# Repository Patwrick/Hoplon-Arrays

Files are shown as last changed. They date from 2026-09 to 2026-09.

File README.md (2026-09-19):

# Hoplon-Arrays

Hoplon-Arrays is a modular cable-routing and cable-management system intended to fit underneath a desk. Silicone units snap onto a separate rigid, 3D-printed panel, which mounts to the desk underside with adhesive. Each unit has a rounded-square pad, a center column, and eight curved support fins. Stem-and-ball posts on the panel have four smaller alignment ribs; matching cores on the mold lid form sockets during casting.

**0.1.0 prototype source release candidate.** This snapshot includes the rev7 source, three checked print candidates, a socketless reference and proposed build instructions. The center-piece STL is withheld because mesh checks found zero-area triangles; there is no complete cleared printable mold set yet. See the [release notes](docs/release-notes.md) for what is included and what is deferred.

The current DIY material is **Shore 40A two-part silicone**; the owner's silicone and mounting-tape links are recorded in the [build guide](docs/build-guide.md#owner-used-materials). A complete physical build record, verified printing settings, and performance test record are still missing. This is a proposed pour-and-cure workflow.

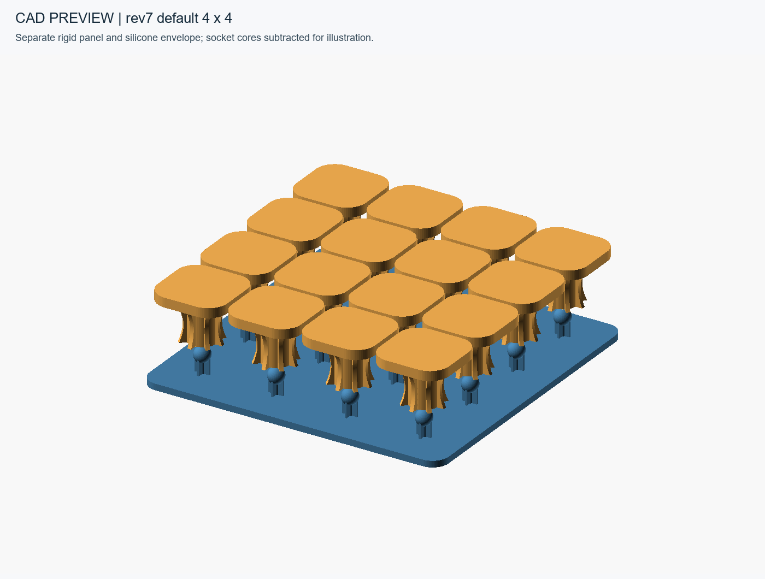
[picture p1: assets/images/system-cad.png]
CAD preview of the separate panel and an exploded array of units


*Current-source CAD preview, shown upright with units lifted above the panel for detail; installed units face downward beneath the desk. The illustration subtracts the shared post geometry to show intended sockets. It is not a photograph or evidence of successful casting.*

## Start here

1. Read the [validation status and file inventory](docs/validation.md) before choosing files. The original root-level STLs and legacy quote package are not the matched release set.
2. Follow the [build guide](docs/build-guide.md) for materials, calculated hardware, printing checks, a small compatibility trial, and the proposed casting sequence.
3. Use the [parameter guide](docs/parameters.md) and [validation commands](docs/validation.md#reproduce-the-checks) to inspect or customize the source. Resolve the center export before treating the outputs as a complete matched set.

You will need an appropriate 3D-printing workflow, measuring tools, mold-fastening hardware, the selected silicone manufacturer's technical and safety documentation, mixing equipment, mounting adhesive, and product-appropriate protective equipment. Product compatibility and printing settings remain to be tested and documented.

## What is included

| Part | Role | Current source / export |
| --- | --- | --- |
| Rev7 parametric source | Canonical mechanical design; millimeters | [system_rev7_perforated_score.scad](system_rev7_perforated_score.scad) |
| Center mold piece | Cavities, two face grooves, four bolt holes | Source mode `center_piece`; STL withheld; see [mesh issue](docs/validation.md) |
| Socket-core lid (`top_lid`) | Ball-and-rib cores enter silicone from the column side | [top_lid.stl](exports/rev7-default/top_lid.stl) |
| Pad-face lid (`bottom_lid`) | Closes the rounded-square pad face | [bottom_lid.stl](exports/rev7-default/bottom_lid.stl) |
| Separate rigid panel | Printed base with the mating post array; never part of the casting mold | [panel.stl](exports/rev7-default/panel.stl) |
| Silicone positive | Visual/cavity-construction envelope only; **no molded socket** | [silicone_positive_reference.stl](exports/rev7-default/silicone_positive_reference.stl); see [validation](docs/validation.md) |

The listed exports are computationally checked candidates for printing trials, not physically validated tooling. Resolve the center-piece mesh issue before treating them as a complete matched mold set. The default configuration is 4 × 4 on 23.4 mm pitch, with a 94.6 mm square panel and 130.6 mm square mold footprint. Scoring/perforation code exists but is **disabled in this set**. No female receivers, carrier array, retaining clips, nut traps, or ejector blocks are required.

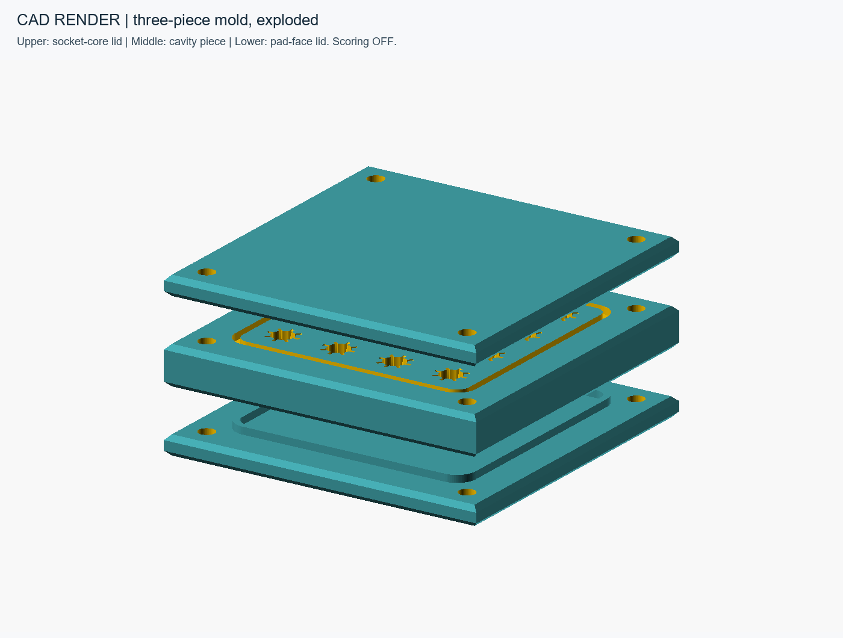
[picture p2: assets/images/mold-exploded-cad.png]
Exploded current-source mold render


*CAD render: socket-core lid above the cavity piece, pad-face lid below. Seating walls enter grooves; their height is not extra closed-stack thickness.*

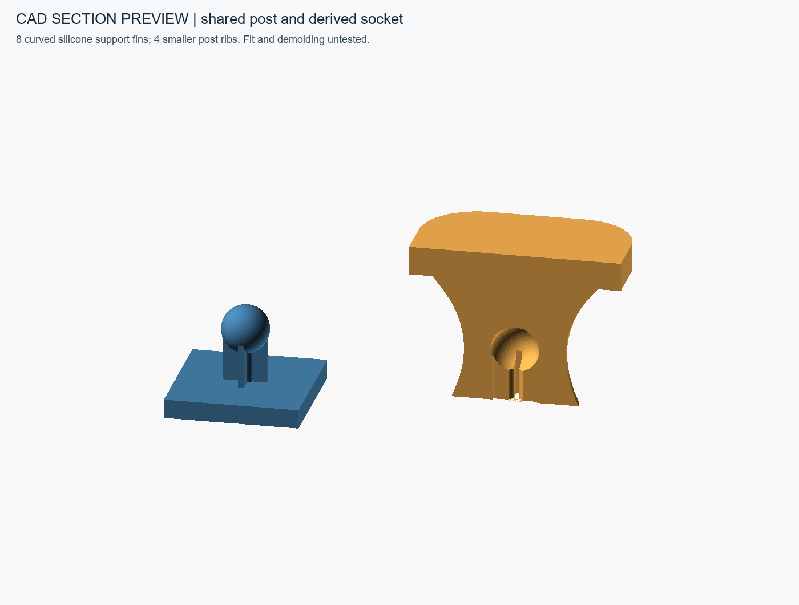
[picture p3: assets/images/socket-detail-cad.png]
CAD cutaway of a socket and the shared post geometry


*Illustrative cutaway derived from the source modules. The four post ribs are distinct from the eight larger silicone support fins. Rendering does not establish fit, release, or durability.*

## Build overview

After resolving the center export and validating a complete matched set, print and inspect the three mold pieces and separate panel. Dry-fit the stack and hardware, then run a small silicone/surface/fit trial. With the pad-face lid beneath the center piece and the column openings accessible, fill before lowering the core lid. Cure according to the chosen product documentation, open the mold, carefully release the sockets, inspect/trim flash, and trial-fit units onto the panel. See the [complete proposed sequence](docs/build-guide.md), including unverified air escape and demolding limits.

The panel's flat back faces the desk underside and the silicone array faces downward. Adhesive-fitting slits in the panel back are a **planned change**, absent from the current CAD and exports; their dimensions and effect on the 2 mm panel need review. Adhesion to the actual desk finish and cable retention are not yet documented as validated.

A demonstration video is planned for a future update. It will show under-desk mounting, cable routing and adjustment, and relevant build steps; no video is available yet. See the [photo and video handoff](docs/photos.md).

## Contributing, evidence, and license

For a geometry or build report, provide the source hash, all parameter overrides, export tool version, affected mode, measurements and units, and reproducible steps. For a physical trial, include material product and batch, print/process settings, and privacy-checked photos. Distinguish source changes, preview artifacts, mesh defects, and fit observations; intentional intersections within Boolean unions are not automatically errors. Propose mechanical changes separately with before/after evidence.

Original project materials are offered under the custom [Hoplon-Arrays Personal and Noncommercial License](LICENSE.md). Personal hobby use, modification and free sharing are permitted with attribution and retained notices. **Business use, including internal business use, sales and paid manufacturing are not licensed** without separate written permission from the applicable rights holder. Third-party materials keep their own terms.

These are custom terms, not an open-source or standard Creative Commons license. Their reach depends on the rights the licensor actually holds; they do not guarantee exclusive control of functional physical parts. See [licensing scope and limitations](docs/licensing.md), and the [release checklist](docs/release-checklist.md) for outstanding publication gates.

The [photo handoff](docs/photos.md) lists the missing physical evidence and reproducible CAD images. [AGENTS.md](AGENTS.md) gives concise maintenance rules.

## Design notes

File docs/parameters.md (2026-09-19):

# Rev7 source and parameters

The canonical design for this preparation is the root [system_rev7_perforated_score.scad](../system_rev7_perforated_score.scad), unchanged during documentation work. The older copy inside the quote package is a different configuration. No original Customizer JSON preset or recorded export override file was found. Comments such as “change to 20” are history, not active parameter values.

All dimensions below are millimeters. The recorded source SHA-256 is `52bff07c70fd33cc4247b62ed5b2c33dbb560772f9617580dee63a37e3ac0839`; this fingerprints the audited working-file bytes, including line endings. The [export manifest](../exports/rev7-default/manifest.json) records every top-level assignment as source text, including derived expressions. Its assignments are provenance, not a Customizer preset. Only `tool_mode` was overridden for the generated candidates. See [validation](validation.md) before treating any candidate as printable.

## Active geometry

| Parameter / result | Current value | Meaning |
| --- | ---: | --- |
| `rows`, `cols` | 4, 4 | 16 separate silicone units / 16 posts |
| `top_size`, `top_corner_radius` | 22, 6 | Rounded-square pad size and corner radius |
| `top_thickness`, `top_bevel_inset` | 3, 0 | Pad thickness; no pad bevel inset |
| `unit_height` | 16 | Silicone positive overall height |
| `edge_gap_x`, `edge_gap_y` | 1.4, 1.4 | Pad-edge gaps |
| `pitch_x`, `pitch_y` | 23.4, 23.4 | Center-to-center array pitch |
| `field_margin_x`, `field_margin_y` | 1.2, 1.2 | Margin beyond outer pads |
| `field_w`, `field_d`, `field_corner_radius` | 94.6, 94.6, 5 | Panel / field outline |
| `column_d` | 9 | Central silicone column diameter |
| Column height | 13 | `unit_height - top_thickness` |
| `fin_count`, `fin_thickness` | 8, 1.2 | Curved silicone support fins; distinct from post ribs |
| `fin_attach_bot_frac`, `fin_attach_top_frac` | 0.60, 0.80 | Fin outer radii 6.6 at column end and 8.8 at pad end |
| `fin_root_overlap`, `fin_end_overlap` | 0.35, 0.20 | Intentional overlaps that join fins to column/pad |
| `fin_neck_extra`, `fin_steps` | 0.10, 40 | Curved-fin profile control and sampling |
| `$fn`, `EPS` | 72, 0.001 | Circular tessellation and Boolean epsilon |

The support-fin profile extends to z = 13.2 in the upright positive and intentionally enters the pad that begins at z = 13. That overlap is part of the union. It is not an unintended loose body or proof of an invalid final solid.

## Shared attachment geometry

Both `top_lid_snap_posts()` and `panel_part()` call **the same `ball_snap_post()` module**. The lid mirrors these posts into the silicone cavity; the separate panel presents them outward for attachment.

| Parameter / result | Current value |
| --- | ---: |
| `snap_stem_d`, `snap_stem_h` | 1.6, 6 |
| `snap_ball_d`, `snap_ball_sink` | 5, 0.4 |
| Ball-center distance from mounting face | 5.6 |
| Nominal post depth / height | 8.1 |
| `snap_fin_enable`, `snap_fin_count` | true, 4 |
| `snap_fin_thickness`, `snap_fin_outer_d` | 0.6, 4.6 |
| `snap_fin_stem_overlap`, `snap_fin_base_overlap` | 0.12, 0.10 |
| `snap_fin_top_clearance`, `snap_fin_tip_taper` | 0.10, 0 |
| Alignment-fin local z limits | −0.10 to 5.50 |
| `panel_thickness` | 2 |
| Nominal panel including posts | 94.6 × 94.6 × 10.1 |

The 72-segment exported ball reaches approximately 8.09762 mm above its mounting face, slightly less than its nominal 8.1 mm extent. Matching CAD posts do not establish a workable printed socket fit: shrinkage, surface finish, cure and printer error remain untested. The source positive **does not subtract this core**, so `silicone_positive` is a visual reference, not a finished socket-bearing part.

## Mold and fastener geometry

| Parameter / result | Current value |
| --- | ---: |
| `mold_wall`, `clamp_flange` | 0, 18 |
| `tool_w`, `tool_d` | 130.6, 130.6 |
| `lid_thickness` | 8 each |
| Center thickness | 16 |
| `mold_edge_bevel` | 2 |
| `cavity_face_relief` | 0.08 |
| `fit_clearance` | 0.20 |
| `bleed_channel_w`, `bleed_channel_depth` | 3, 3 on both faces |
| Seating-wall nominal section | 2.6 wide, 3 high; 0.2 clearance at each side |
| `bolt_hole_enable`, count | true, 4 aligned through-holes |
| `bolt_hole_d`, `bolt_edge_margin` | 6.7, 7.5 |
| Hole center coordinates | x = ±54.45, y = ±54.45 |
| Hole center spacing | 108.9 × 108.9 |
| Closed stack at bolt line | 8 + 16 + 8 = **32** |

The closed assembly uses center z = 0…16, bottom-lid exterior z = −8, and top-lid exterior z = 24. The walls nest inside the center's channels; their 3 mm heights must not be added again to the bolt stack. Export-wrapper z positions differ from assembled positions: bottom lid 0…11; center 0…16; top lid approximately 0.00238…16.1. These file heights are not additive for fastener sizing.

The 6.7 mm CAD hole is a clearance hole, not an M6.7 thread. A calculated candidate is four M6 × 45 bolts (under-head length), four matching M6 nuts and eight flat washers. The [build guide](build-guide.md#bolt-length-and-clearance) records the standards-based washer/nut assumptions, length calculation and required fit trial. There are no nut traps. A 12 mm washer outside diameter fits on the outer planar face: each bolt center is 8.85 mm from the bevel's planar boundary, giving 2.85 mm margin beyond a 6 mm radius washer. Check actual head/washer dimensions and printed surfaces before purchase/use.

There are perimeter overflow trenches on both center faces and matching seating walls. There is **no dedicated injection port or explicit local vent channel from each cavity to those perimeter trenches**. Filling and air escape during closure remain a physical test requirement.

## Scoring features are currently off

`score_enable = false`, `score_top_enable = false`, and `score_bottom_enable = false`. Therefore none of the matched scoring teeth or pockets appears in the audited default set. `score_dot_enable = true` alone does not activate them.

The dormant values are: offset 1.2, continuous line width 0, pocket depth 0.60, web target 0.08, derived tooth height 0.52, fit clearance 0.20, dot diameter 0.80, side-dot pitch 4 and column-side dot count 18. These are experimental controls, not a demonstrated tear specification. Activating them requires coordinated regeneration of the center and corresponding lids and inspection for unintended collisions, clearance and flash behavior. Do not turn them on merely to match an older filename.

## Modes and customization

| `tool_mode` | Result |
| --- | --- |
| `silicone_positive` (source default) | 16 separate solid external positives; sockets absent |
| `center_piece` | Cavity block; current STL quality gate unresolved |
| `top_lid` | Socket-forming core lid and seating wall |
| `bottom_lid` | Pad-face closure and seating wall; no block ejectors |
| `panel` | Separate rigid panel with 16 posts |
| `exploded_mold` | Visual assembly reference only |
| `exploded_system` | Visual mold, solid positives and separate panel |

The source's final `else` also selects `exploded_system` for an unrecognized string; a typo can silently export the wrong scene. The supplied export script restricts modes to named individual parts/reference models.

To explore a change, retain the canonical file and work on a clearly named local copy. Record all overrides, regenerate every affected mating part, and repeat dimensional, topology and physical-fit checks. Row/column count, pitch, pad/column dimensions, posts, channels and score settings are mechanically coupled. No supported parameter range or tolerance budget has been validated. Keep the original external pad/column/eight-fin structure unless an owner-approved mechanical change explicitly replaces it.

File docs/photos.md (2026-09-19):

# Photos, CAD images and future video

No physical prototype photos were present in the inspected repository. The three current images are generated from the canonical source, with no photographic or test claims. Do not substitute the old quote drawings or concept art for current-model evidence.

## Existing CAD images

| File | View and caption | Location |
| --- | --- | --- |
| [system-cad.png](../assets/images/system-cad.png) | CAD preview: separate rigid panel and lifted 4 × 4 silicone array; shared post geometry subtracted for illustrative sockets | README main image |
| [mold-exploded-cad.png](../assets/images/mold-exploded-cad.png) | CAD render: core lid / center piece / pad-face lid in assembly orientation, separated for visibility; default scoring off | README and build-guide orientation reference |
| [socket-detail-cad.png](../assets/images/socket-detail-cad.png) | CAD preview section: derived socket and shared ball post; eight support fins versus four post ribs | README and build-guide fit reference |

Run `python scripts/render_cad.py --openscad openscad` from the repository root (OpenSCAD and Pillow required). The script reads the unchanged SCAD and replaces only its view dispatch in a temporary file. The system scene lifts socketed unit envelopes 10 mm above their nominal panel seating plane. The socket illustration subtracts `ball_snap_post()` from `silicone_unit()` and cuts away half for visibility; that is a documentation view, not a new production source mode. The exploded mold uses the source assembly modules with spacing for visibility. The script does not edit the SCAD.

The [render manifest](../assets/images/render-manifest.json) records the source hash, OpenSCAD version, scenes, camera settings, and output hashes. Main/detail images use OpenCSG previews; the exploded mold uses CGAL rendering. Previews may have display artifacts. The rendered images have been opened and checked visually; they contain no desktop, faces, labels from private correspondence, or copied image metadata. Each is freshly written as an RGB PNG without source EXIF or location fields.

## Photos still needed

These filenames are planned handoff names, not links to missing files. Save reviewed copies under `assets/images/` only after removing private details and metadata. Preserve unredacted originals outside the public repository.

| Planned filename | View | Proposed caption | Placement | Must demonstrate |
| --- | --- | --- | --- | --- |
| `panel-assembled-photo.jpg` | Under-desk three-quarter and side view with routed cables | Physical cable-management prototype under a desk, [material/product], [test date], [configuration] | README main image beside CAD | Desk attachment, separate rigid panel and attached units, cable path and clearance; no performance inference |
| `panel-adhesive-photo.jpg` | Panel back before mounting and its contact with the desk underside | Adhesive mounting trial with [tape identity], [desk finish], [configuration] | Build-guide mounting step | Actual tape layout, contact area and access; identify whether any future slits are present |
| `unit-separated-photo.jpg` | Single demolded unit, pad and underside | One cast Shore 40A unit before assembly | Build guide inspection | Rounded-square pad, center column, eight curved support fins; scale included |
| `socket-post-photo.jpg` | Macro of socket beside a post, additional underside angle | Molded socket and four post alignment ribs | README attachment detail / fit step | Socket opening and keyed recesses; all four ribs identifiable across views; defects visible |
| `mold-three-pieces-photo.jpg` | Both faces of all three printed pieces | Printed mold parts, labeled by contacting silicone face | Build guide orientation | Core lid, center cavity openings, pad-face lid, both bleed grooves and seating walls |
| `bolt-stack-dry-fit-photo.jpg` | Side of closed stack plus one measured corner | Dry fit with four through-bolts, washers and nuts | Build guide hardware | Measured 32 mm nominal corner stack, seated faces, actual head/washer clearances and thread projection |
| `mold-open-fill-photo.jpg` | Center on pad-face lid before closing, then partly lowered core lid | Proposed filling sequence in a documented trial | Build guide filling | Open cavity access, fill level and observed air/overflow paths; panel outside mold |
| `demolding-photo.jpg` | Lid opening and socket being gently released in separate frames | Physical demolding trial, [material/process] | Build guide demolding | Actual release direction, ball undercut, tool placement and any tears or broken posts |
| `flash-detail-photo.jpg` | Macro before and after trimming with scale | Flash result, scoring [off / exact enabled configuration] | Build guide flash / validation | Flash thickness/bridges, any scoring marks and damage; manual trimming distinguished from tearing |

Capture an uncropped context view as well as each close-up. Record source hash, parameters, printer/material/process, silicone product, cure schedule, release treatment, and trial outcome alongside the image. Avoid identifiable people, shipping labels, supplier screens, correspondence, home/work location, serial numbers, and background reflections. Inspect EXIF/GPS, author fields, filenames, embedded thumbnails, and visible text before publication. Obtain permission for any identifiable person or third-party image. A cleaned image does not remove private metadata from older Git objects or original copies.

## Future demonstration video

The owner plans to add a video in a future update. No recording or public URL is available yet; do not add a broken embed or present the CAD views as filmed results. A suggested working filename is `hoplon-arrays-under-desk-demo.mp4`, with the public caption “Hoplon-Arrays: under-desk mounting and cable routing — [configuration/date].” Add its reviewed link to the README and build guide once available.

Suggested sequence:

1. Establish the underside of the desk, the cable route and the intended panel location.
2. Show the separate panel, one silicone unit and the snap/socket interface; identify the actual silicone and adhesive used.
3. Show the panel back, adhesive placement and mounting. If adhesive-fitting slits have been added in a later revision, identify that revision rather than implying the current files contain them.
4. Demonstrate placing, adjusting and removing cables, showing the panel attachment and unit behavior without claiming an unmeasured load or life rating.
5. Include short build clips if available: three mold pieces, open filling, cure conditions, demolding and flash inspection. Label any unfilmed steps as proposed.

Record the source/configuration, material batches, desk finish, print settings and relevant measured results in the video description. Review visible backgrounds, screens, shipping labels, audio, faces and video/container metadata before publication. Use only owned or authorized footage/music. A demonstration documents the shown trial; it does not establish general performance.

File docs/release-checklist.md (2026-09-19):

# 0.1.0 release candidate checklist

**Prepared scope: first prototype source release, 0.1.0. Publication is not authorized.** The owner has requested preparation with the current files and later updates. [Release notes](release-notes.md) and [changelog](../CHANGELOG.md) make that limited scope explicit. No push, tag, hosted release, visibility change, history rewrite, staging or commit is part of this preparation. The review archive is a file allowlist, not a Git history export.

## Publication blockers / owner decisions

- [ ] Approve public disclosure and the exact proposed files in [release-files.txt](release-files.txt). Review the actual ZIP and its `REVIEW-MANIFEST.json` before publishing.
- [x] Add the owner-requested personal/noncommercial license, excluding business and profit-making permission. [LICENSE.md](../LICENSE.md) and the [scope notes](licensing.md) distinguish CAD/hardware, scripts, documentation and assets, preserve third-party terms and explain functional-hardware limits.
- [ ] Confirm the authority to license each included contribution and its required attribution. The custom license is added; ownership and third-party clearance are not established by adding it. Legal review of the wording is advisable, particularly for physical-product restrictions. Do not describe this restricted-use project as open source.
- [ ] If publishing Git history, approve or remediate its owner-linked author attribution. Deletion or `.gitignore` changes cannot remove old Git objects. If attribution must change, review a separately authorized, backed-up history-remediation plan first; no rewrite has been run. The curated file archive contains no Git author metadata.
- [ ] If publishing Git history, review the intended branch and reachable objects explicitly. Earlier captured/local objects still retain excluded legacy material, including an embedded personal path; auxiliary refs and reflogs change as local tools operate. The refreshed audit found prepared-file snapshots in current auxiliary refs and older legacy objects retained locally, including unreachable objects. Do not publish the `.git` directory, a mirror or an all-ref bundle. No local objects or refs have been purged.
- [x] Exclude the entire original legacy quote package from this candidate. STEP geometry and drawings are unverified and differ from current SCAD; an earlier overlap concern remains unresolved. The bundled executable and bytecode also have privacy/redistribution concerns. They remain private local references pending any separate review.
- [x] Prepare the current files as a prototype source release with the limitations in [validation](validation.md) documented. The center STL and physical validation are deferred; they prevent a complete-printable-kit or proven-build claim, not preparation of this honestly limited source snapshot. Mechanical changes remain separate proposals.
- [ ] Authorize publication explicitly. Preparing this candidate does not authorize publishing the repository or archive.

## Before claiming a demonstrated DIY build

- [ ] Resolve the center-piece export's zero-area triangles and validate a complete matched set before advertising a complete printable mold download. This requires an explicit export/triangulation investigation; no automatic mesh or mechanical repair was applied.
- [x] Record the owner-approved under-desk cable-management purpose and owner-used silicone/adhesive links in the [build guide](build-guide.md#owner-used-materials).
- [ ] Confirm the supplied BBDINO 40A variant and record matching official technical/SDS revisions. Complete unresolved product-specific fields in the [build guide](build-guide.md).
- [ ] Record printer/material/process and verified orientations; inspect sealing, post/rib detail, support access and dimensions.
- [ ] Dry-fit the calculated four M6 × 45 mm fasteners, four nuts and eight washers with the actual hardware. Confirm the 32 mm nominal bolt-line stack, full lid seating, head/washer clearance and thread engagement.
- [ ] Run a surface/cure compatibility sample and one-cavity fill, demold and snap-fit trial. Observe air escape, complete pad/fin fill, release from the ball cores and any damage.
- [ ] Measure overflow and handling loss before selecting a full casting batch. Use documented product density before any volume-to-mass conversion.
- [ ] If enabling scoring, regenerate a matched set and test interference, flash and trimming. Default scoring is off. No precise/tool-free tear is demonstrated.
- [ ] Confirm exact mounting-tape identity/dimensions and manufacturer application guidance; trial adhesion to the actual printed panel and desk finish before making mounting or cable-load claims.
- [ ] Add the physical evidence in [photos](photos.md), including failures and dimensions. Complete physical tests before changing claims; CAD checks alone do not certify printability, fit, cure compatibility, durability, or suitability for a particular use.

These process items may remain openly documented prototype limitations if the owner approves a prototype-only source release; they block claims of a proven build.

## Preparation checks

- [x] Record `0.1.0` in [VERSION](../VERSION), prepare [release notes](release-notes.md) and a [changelog](../CHANGELOG.md), and identify the mechanical design as rev7.
- [x] Original CAD, STLs and quote assets retained in place. No original geometry changed.
- [x] Canonical source and default values read; old exports distinguished from regenerated ones.
- [x] Local current/staged/untracked files and locally available Git objects/metadata inspected. Detailed redacted audit evidence kept outside the publishable repository.
- [x] No likely credentials found by the local checks performed. This is bounded scan coverage, not a guarantee. Any subsequently discovered real credential requires owner rotation/revocation as well as cleanup.
- [x] Current-source images generated and reviewed; original physical photos were absent. New image metadata checked.
- [x] Quote package and original root STLs excluded by explicit archive allowlist and local ignore rules. Ignore rules are not history cleanup.
- [x] Harden archive construction to reject changed source/assets, failed or unmanifested export candidates, path traversal and symlink/junction paths. Preserve SCAD and binary bytes with [Git attributes](../.gitattributes).

The local audit included normal branch refs, auxiliary capture refs, reflogs, all available objects, commit identity fields, and local origin configuration. Remote server state, hosted releases, LFS servers, forks, other clones, and cloud copies were not accessed. New captured objects or refs may be created by local tooling after the audit; recheck immediately before any Git publication. Original CAD/STEP/PDF metadata and the bundled executable received supported local inspection; see the private audit handoff for exact limitations. Never upload private originals to a scanning service.

## Build and inspect the review archive

The [packaging script](../scripts/package_review.py) checks local Markdown targets/anchors, the exact file list, and source/export/image hashes against the provenance manifests. It rejects failed or unrecorded mesh/image assets and symlinks/junctions. `--check` performs validation without writing a ZIP. `--output` requires a new ZIP path **outside the repository**, writes the checked file bytes plus an internal manifest, then rereads the archive to check names, CRCs and member hashes. The manifest records the proposed version; it does not imply that a Git tag or release exists. The script refuses overwrites and never publishes.

```sh
python -B scripts/package_review.py --check
python -B scripts/package_review.py --output ../Hoplon-Arrays-release-review/Hoplon-Arrays-0.1.0-prototype-review.zip
```

After any edit, create a new candidate filename and inspect it again. Do not zip the repository directory wholesale: `.gitignore` does not control an arbitrary ZIP operation. Exclude `.git`, originals/backups, supplier correspondence, raw/private audits, executable installers and bytecode. Review staged changes independently before an eventual commit.

## Publication handoff after owner approval

1. Approve the exact package contents, rights/attribution and applicable Git-history scope above. Preserve the excluded originals and private review records.
2. If publishing the repository, stage only the explicit paths in `release-files.txt` after removing its comment lines; inspect that exact staged set and approve a commit. Do not use a blanket add or publish auxiliary refs. No files are staged by the preparation scripts.
3. Use the reviewed `0.1.0` notes for the initial prototype release and identify it as a prerelease/experimental snapshot. Create a tag or hosted release only after explicit authorization; use an explicitly approved branch/ref for any push.
4. Attach the inspected curated archive and its checksum, rather than an unreviewed working-directory ZIP. Check the final hosted files and links after publication. Replace the notes' "not yet published" status and changelog's prepared status only when publication actually occurs.

The missing photos/video, slit design, selected-product process documents and physical tests remain future work. Do not silently turn those omissions into assertions of validation when preparing the public description.

## Optional improvements after the gates

- Add physical build photos and measured results as evidence becomes available.
- Add the planned under-desk demonstration video when available, following the [photo/video handoff](photos.md#future-demonstration-video).
- Review the planned panel-back adhesive-fitting slits, establish dimensions and validate a new panel revision before documenting them as implemented. See the [pending geometry proposal](validation.md#planned-panel-mounting-change).
- Add a selected-product batch worksheet once density and measured losses are known.
- Expand mesh checks with an independent self-intersection/solid validator and slicer review.
- Add tested print profiles and a reproducible compatibility/retention test protocol.
- Consider geometry changes only through a separately reviewed proposal with affected files, measured defects and validation criteria.

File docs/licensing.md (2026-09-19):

# Licensing and reuse

The owner requested permission for personal/noncommercial use without granting business or profit-making use. [LICENSE.md](../LICENSE.md) implements that direction with **custom terms**. It is not a standard Creative Commons license or an open-source license. This page explains the scope; the license text contains the operative terms.

| Material | Applied terms / limit |
| --- | --- |
| Original SCAD and released CAD exports | Personal/noncommercial license, to the extent the rights holders can grant permission |
| Original Python scripts | Same license; personal execution, modification and free sharing permitted, business use excluded |
| Original documentation and CAD images | Same license with attribution and preserved notices |
| Physical parts made from the design | Personal making/use and free gifts are permitted under rights the Licensor holds; no business or paid manufacturing permission is granted |
| Third-party dependencies, websites, product documents and separately licensed material | Their own terms; not relicensed by this project |
| Excluded legacy quote package and unverified original assets | Not added to the public package or granted redistribution permission by this change |

For permitted sharing, credit **Hoplon-Arrays**, retain the license and existing notices, identify changes, and include the source repository link when available. No personal name, new company owner or public contact address has been invented. For use outside the grant, obtain separate written permission from the applicable rights holder; none is included here.

## Why custom terms

Creative Commons' NonCommercial condition considers the purpose of a use; an entity's for-profit status alone does not decide whether it complies. CC also recommends against applying its licenses to software. The owner's request excludes business use itself, including internal use, and covers CAD plus scripts, so this project uses explicitly labeled custom wording. [CC NonCommercial explanation](https://creativecommons.org/faq/#does-my-use-violate-the-noncommercial-clause-of-the-licenses), [CC software guidance](https://creativecommons.org/faq/#can-i-apply-a-creative-commons-license-to-software)

Business-use restrictions are incompatible with the Open Source Definition; describe the project as available for personal/noncommercial use, not open source. [Open Source Definition, section 6](https://opensource.org/osd)

## Legal limits and contribution review

A license cannot create rights its licensors do not hold. In particular, US copyright law limits protection of the mechanical/utilitarian aspects of useful articles; copyright in drawings does not automatically provide an exclusive manufacturing right. Consequently, this license alone does not guarantee control over every commercial use of the physical cable-management hardware. No patent or registered design right has been verified for this project. [U.S. Copyright Office: useful articles](https://www.copyright.gov/register/va-useful.html)

This is custom drafting, not a legal opinion or a guarantee of enforceability. Legal review is advisable before relying on it, particularly for restrictions concerning functional hardware. Before publication, confirm the authority to license every included contribution and preserve applicable third-party notices. Before accepting future contributions, confirm the contributor is entitled and willing to offer them under these terms; ownership is not automatically assigned to the maintainer. Publication, identity/privacy review and mechanical-validation gates remain separate from adding a license.

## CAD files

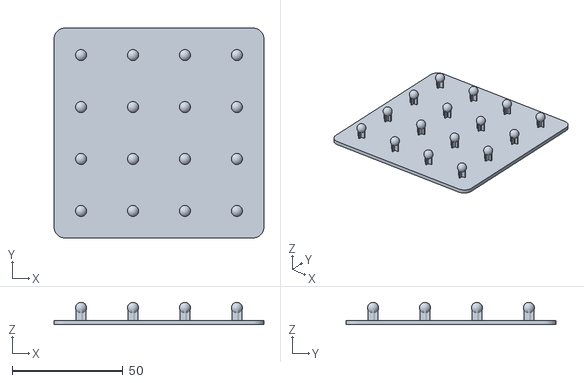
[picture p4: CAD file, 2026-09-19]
exports/rev7-default/panel.stl
94.6 x 94.6 x 10.1

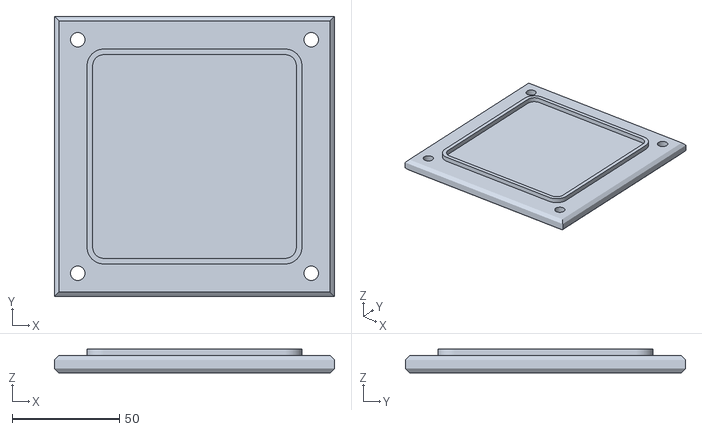
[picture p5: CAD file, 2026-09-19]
exports/rev7-default/bottom_lid.stl
130.6 x 130.6 x 11.0

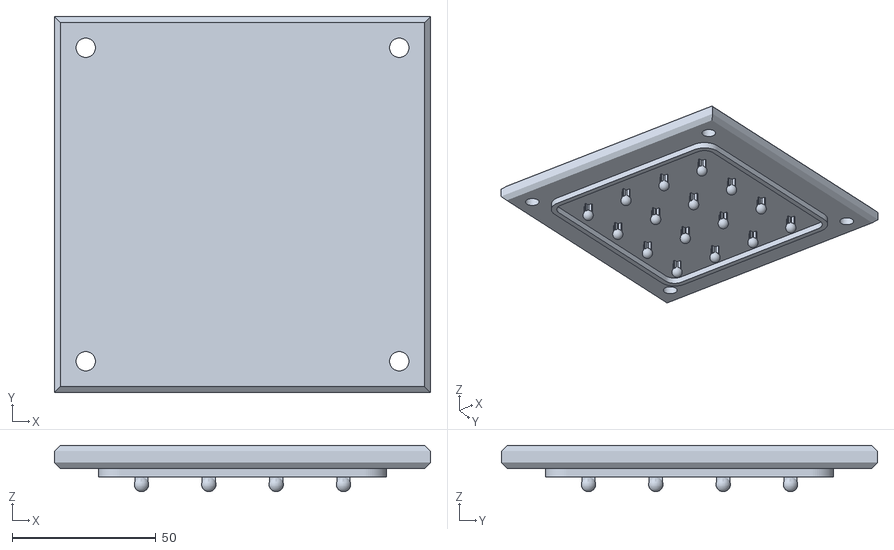
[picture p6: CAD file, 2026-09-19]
exports/rev7-default/top_lid.stl
130.6 x 130.6 x 16.1

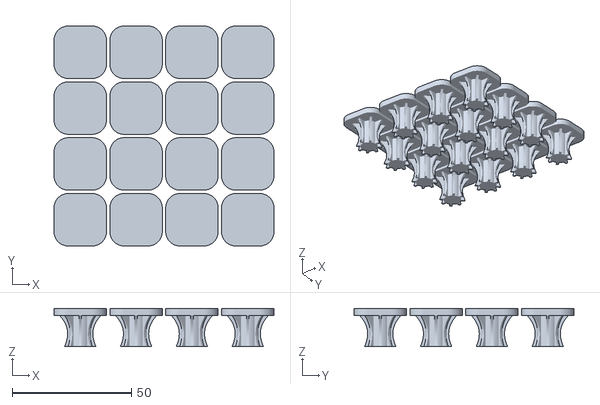
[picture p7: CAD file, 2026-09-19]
exports/rev7-default/silicone_positive_reference.stl
92.2 x 92.2 x 16.0

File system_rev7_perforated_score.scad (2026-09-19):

// Cleaned clip-unit + mold + panel system
//
// What this version does:
// - Removes the molded panel backing entirely.
// - Keeps the original pad + column + fin unit structure.
// - Adds a separate PRINTED panel with ball-snap posts.
// - Uses ball-post geometry directly on the TOP LID to create molded snap sockets.
// - Uses the same ball-post geometry on the final printed panel.
// - Adds 4 alignment fins/ribs on each ball-post stem for orientation/keying.
// - No insert carrier array is used in this revision.
// - The bottom lid is flat.
// - The center mold has bleed channels on BOTH faces.
// - Both lids get matching seating walls that fit into the bleed channels.
// - Adds real matched score teeth + pockets around the top and bottom parting-face edges.
// - Variables are grouped at the top and unused legacy modules were removed.
//
// Suggested workflow:
// 1) Print top lid, center piece, bottom lid.
// 2) Fill/close mold with silicone in the cavities; overflow gets captured in bleed channels.
// 3) The top-lid ball posts create the pop-in/pop-out socket shape in the silicone.
// 4) Demold the silicone units.
// 5) Print the separate panel with the same ball-post array and snap the silicone units onto it.

$fn = 72;
EPS = 0.001;

// ============================================================
// TOOL / VIEW
// ============================================================
tool_mode = "silicone_positive";
// "silicone_positive", "center_piece", "top_lid", "bottom_lid",
// "panel", "exploded_mold", "exploded_system"

show_exploded_gap = 18.0;

// ============================================================
// ARRAY / UNIT GEOMETRY
// ============================================================
rows = 4;
cols = 4;

top_size          = 22.0; //change to 20, already printed top_lid.
top_corner_radius = 6.0;
top_thickness     = 3.0; //3.4
top_bevel_inset   = 0.0;

unit_height       = 16.0;

edge_gap_x        = 1.40; //1.2
edge_gap_y        = 1.40; //1.2
pitch_x           = top_size + edge_gap_x;
pitch_y           = top_size + edge_gap_y;

field_margin_x    = 1.2;//3.8
field_margin_y    = 1.2;
field_corner_radius = 5.0;

// ============================================================
// COLUMN / FIN GEOMETRY
// ============================================================
column_d             = 9.0;//8
fin_count            = 8;
fin_thickness        = 1.2;
fin_neck_extra       = 0.10;
fin_attach_bot_frac  = 0.60; //0.60
fin_attach_top_frac  = 0.80; //0.99
fin_root_overlap     = 0.35;
fin_end_overlap      = 0.20;
fin_steps            = 40;

// ============================================================
// MOLD GEOMETRY
// ============================================================
mold_wall          = 0.0; //4.0
clamp_flange       = 18.0;
lid_thickness      = 8.0;

// Chamfer on outside edges of center_piece, top_lid, and bottom_lid.
// This gives a small pry/spatula lead-in at the mold split lines.
mold_edge_bevel    = 2.0;

// Tiny overcut at the two mold faces to prevent exact-coplanar preview skins
// from making the center-piece cavities look closed.
cavity_face_relief = 0.08;

fit_clearance      = 0.20;

bleed_channel_w    = 3.0;
bleed_channel_depth= 3.0; //3.0

// Flash scoring / perforation control.
// Previous revision made a gutter, which could make the flash thicker.
// This version creates MATCHED mold teeth + pockets. The remaining silicone
// between them is controlled by score_web_thickness, like dotted rip-paper.
score_enable          = false; // true
score_top_enable      = false;   // silicone top-pad side / bottom_lid side
score_bottom_enable   = false;   // ball-post/column side / top_lid side //true

score_offset          = 1.2;   // distance from actual part edge before score line begins
score_line_width      = 0.0;   // width of continuous score rib
score_pocket_depth    = 0.60;   // depth of matching pocket cut into center piece
score_web_thickness   = 0.08;   // silicone left between lid tooth and center pocket
score_tooth_height    = max(score_pocket_depth - score_web_thickness, EPS);

score_fit_clearance   = 0.20;   // extra XY clearance so score teeth fit into pockets
score_dot_enable      = true;   // adds dotted/perforated rip-paper style teeth
score_dot_d           = 0.80;
score_dot_pitch       = 4.00;   // spacing for square-side dots
score_dot_count       = 18;     // circular dots around column/ball side

bolt_hole_enable   = true;
bolt_hole_d        = 6.7; //6.8
bolt_edge_margin   = 7.5;

// shared ball-snap post geometry
// Used on BOTH the top lid and the final printed panel.
snap_stem_d        = 1.6;
snap_stem_h        = 6; //1.8
snap_ball_d        = 5.0;
snap_ball_sink     = 0.4;  // how much the ball blends into the stem 0.6

// 4 alignment fins/ribs that run up the stick toward the ball.
// Used on BOTH the top lid and the final printed panel because both use ball_snap_post().
snap_fin_enable        = true;
snap_fin_count         = 4;
snap_fin_thickness     = 0.6;  // tangential fin thickness
snap_fin_outer_d       = 4.6;   // how far the fins extend outward from the stem center
snap_fin_stem_overlap  = 0.12;  // radial overlap into the stem so fins print as one body
snap_fin_base_overlap  = 0.10;  // z-overlap into lid/panel surface for stronger base fusion
snap_fin_top_clearance = 0.10;  // gap before ball blend area
snap_fin_tip_taper     = 0.00;  // top of fin narrows slightly as it reaches the ball
// ============================================================
// PANEL GEOMETRY
// ============================================================
// The final panel uses the SAME ball-post structure as the top lid.
panel_thickness       = 2.0;

// ============================================================
// DERIVED
// ============================================================
field_w = (cols - 1) * pitch_x + top_size + 2 * field_margin_x;
field_d = (rows - 1) * pitch_y + top_size + 2 * field_margin_y;

tool_w  = field_w + 2 * mold_wall + 2 * clamp_flange;
tool_d  = field_d + 2 * mold_wall + 2 * clamp_flange;

pad_top_face_size = max(top_size - 2 * top_bevel_inset, 0.1);
pad_top_face_r    = max(top_corner_radius - 0.55 * top_bevel_inset, 0.25);

snap_post_drop = snap_stem_h - snap_ball_sink + snap_ball_d / 2;

bolt_x = tool_w / 2 - bolt_edge_margin - bolt_hole_d / 2;
bolt_y = tool_d / 2 - bolt_edge_margin - bolt_hole_d / 2;

// ============================================================
// HELPERS
// ============================================================
function clamp(v, lo, hi) = min(max(v, lo), hi);
function bez2(t, p0, p1, p2, p3) = [
    pow(1 - t, 3) * p0[0] + 3 * pow(1 - t, 2) * t * p1[0] + 3 * (1 - t) * pow(t, 2) * p2[0] + pow(t, 3) * p3[0],
    pow(1 - t, 3) * p0[1] + 3 * pow(1 - t, 2) * t * p1[1] + 3 * (1 - t) * pow(t, 2) * p2[1] + pow(t, 3) * p3[1]
];
function bezier_pts(p0, p1, p2, p3, steps=16) = [for (i = [0:steps]) bez2(i / steps, p0, p1, p2, p3)];
function fin_angles(n) = [for (i = [0 : n - 1]) i * 360 / n];

module rounded_rect_2d(w, d, r) {
    rr = clamp(r, 0.01, min(w, d) / 2 - 0.01);
    offset(r = rr)
        square([max(w - 2 * rr, 0.01), max(d - 2 * rr, 0.01)], center = true);
}

module rounded_square_2d(s, r) {
    rounded_rect_2d(s, s, r);
}

module field_outline_2d() {
    rounded_rect_2d(field_w, field_d, field_corner_radius);
}

module place_units() {
    for (r = [0 : rows - 1])
        for (c = [0 : cols - 1])
            translate([
                (c - (cols - 1) / 2) * pitch_x,
                (r - (rows - 1) / 2) * pitch_y,
                0
            ])
                children();
}

module bleed_channel_2d() {
    difference() {
        offset(delta = bleed_channel_w)
            field_outline_2d();
        field_outline_2d();
    }
}

module seal_wall_2d(clearance = fit_clearance) {
    difference() {
        offset(delta = max(bleed_channel_w - clearance, EPS))
            field_outline_2d();
        offset(delta = clearance)
            field_outline_2d();
    }
}

module corner_bolt_holes(z0, h) {
    if (bolt_hole_enable && bolt_hole_d > EPS)
        for (sx = [-1, 1])
            for (sy = [-1, 1])
                translate([sx * bolt_x, sy * bolt_y, z0])
                    cylinder(h = h, d = bolt_hole_d);
}

module beveled_tool_body(h) {
    b = clamp(mold_edge_bevel, 0, min(min(tool_w, tool_d) / 2 - EPS, h / 2 - EPS));
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

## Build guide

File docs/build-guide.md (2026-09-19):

# DIY build guide: Shore 40A silicone

This is a **proposed prototype workflow**, derived from the current rev7 CAD. A documented physical casting, print profile, socket-fit trial, and Shore 40A performance test have not been established. Review [validation](validation.md) before buying materials or printing. This is a two-part silicone pour-and-cure process; the older industrial LSR quote workflow is not the DIY process.

The intended application is cable routing and management underneath a desk. The rigid panel attaches to the desk underside using mounting adhesive, with the silicone units facing downward. The owner has identified the materials used below; this records their selection without claiming a documented load, adhesion or durability test.

### Owner-used materials

| Material | Owner-provided product link | Documentation status |
| --- | --- | --- |
| Silicone | [BBDINO 40A clear silicone kit, ASIN B0FHHBGSQK](https://www.amazon.com/dp/B0FHHBGSQK) | Matches the manufacturer's 1.1 kg / 2.42 lb 40A clear product; nominal manufacturer specifications and remaining documentation gaps are below. |
| Panel mounting adhesive | [Mounting tape, ASIN B0FPQ3VWPB](https://www.amazon.com/dp/B0FPQ3VWPB) | Owner-reported panel adhesive; confirm exact tape grade, supplied dimensions and application instructions from its packaging/manufacturer. |

Links were checked on 2026-09-19 and have shopping-history/tracking parameters removed. These are product references, not affiliate links or evidence of supplier endorsement. Verify the supplied variant and batch; a marketplace listing is not a substitute for a matching technical datasheet or SDS.

The adhesive listing needs clarification: its selected title/variant says 0.39 inch × 10 feet, while shared details mention 2 inch / 50 mm width. The title invokes 3M, but the brand/manufacturer fields identify P7yaumy, and the title and bullets disagree on removable versus permanent bonding. Treat this as the owner's exact purchase reference, not a verified 3M grade. Measure the actual roll and confirm packaging/instructions before sizing the planned slits or specifying installation conditions. No attributable manufacturer instructions were located for this tape during this review. [Owner-linked tape listing](https://www.amazon.com/dp/B0FPQ3VWPB)

## 1. Choose a matched set

Use the root [rev7 source](../system_rev7_perforated_score.scad), the configuration in [parameters](parameters.md), and the regenerated exports listed in [validation](validation.md). Do not combine the original root-level STLs, quote-package files, or differently sized exports with this set. A filename or a comment that a lid was printed does not establish matching dimensions.

**Current gate:** the regenerated center-piece STL has zero-area triangles and is withheld from the printable-download list. Resolve and validate that export before a full build; the following is a proposed procedure for a complete matched set, not a claim that all required print files are cleared.

The default model has 16 units in a 4 × 4 array. Each unit has a nominal 22 × 22 mm rounded-square pad, 3 mm pad thickness, 16 mm overall height, a 9 mm center column, and **eight curved support fins**. The distinct attachment post has **four small alignment ribs**. Unit pitch is 23.4 mm in both directions. Dimensions are millimeters; STL does not encode units, so verify the slicer imports millimeters without scaling.

| Part | Quantity | Purpose / source mode |
| --- | ---: | --- |
| Center piece (export withheld) | 1 | Printed cavity tooling; source mode `center_piece`; resolve [mesh issue](validation.md) first |
| [Top lid](../exports/rev7-default/top_lid.stl) | 1 | Printed tooling carrying socket-forming ball cores; `top_lid` |
| [Bottom lid](../exports/rev7-default/bottom_lid.stl) | 1 | Printed pad-face closure; `bottom_lid` |
| [Rigid panel](../exports/rev7-default/panel.stl) | 1 | Separate final component carrying attachment posts; `panel` |
| Owner-linked BBDINO 40A two-part silicone | Trial, then measured batch | Product link above; manufacturer instructions, quantity and compatibility still require verification |
| Owner-linked panel mounting tape | Amount/layout to establish in a mounting trial | Applies to the rigid panel back and desk underside; not silicone or mold assembly |
| M6 × 45 mm fully threaded bolts, 1 mm pitch | 4 | Calculated candidate, under-head length; see below |
| Matching M6 nuts, 5 mm thick for this calculation | 4 | External nuts; no modeled nut traps |
| M6 flat washers, 6.4 mm ID × 12 mm OD × 1.6 mm thick | 8 | One under each bolt head and one under each nut |

Also prepare a suitable printer and slicer, calipers, matched tools for the fasteners, a stable protected work surface, compatible mixing containers and stirrers, the measuring equipment specified by the chosen silicone, a timer, a blunt opening spatula, trimming tools, and the PPE required by the materials' safety data sheets. Surface sealer and release treatment depend on compatibility and trial results. BBDINO calls for vacuum degassing for this product; suitable equipment and its detailed procedure must be established before mixing.

The panel is not part of the silicone mold. The `silicone_positive` mode is an external-shape reference: **it contains no subtracted socket** and is neither the finished silicone part nor a print required for assembly. There are no printed female receivers, carrier array, carrier holes, retaining clips, or block ejector inserts in this bill of materials.

### Bolt length and clearance

The source creates four aligned **6.7 mm CAD clearance holes**, not M6 threads. Their centers are at X/Y = ±54.45 mm. The nominal closed mold thickness at those holes is:

```text
bottom lid body + center body + top lid body = 8 + 16 + 8 = 32 mm
required under-head length = closed stack + washers + nut thickness + projection
                          = 32 + (2 × 1.6) + 5 + 2 = 42.2 mm
candidate standard length = 45 mm
nominal projection beyond the 5 mm nut = 45 − 32 − 3.2 − 5 = 4.8 mm
```

Nut thickness must be **added** to the required bolt length: the nut sits outside the stack and occupies threaded length. A formula subtracting nut thickness would under-size the bolt. The 2 mm projection is a calculation allowance, not a tested engagement requirement. The seating walls nest into the center piece, so their 3 mm height is not added again.

Candidate dimensions are supported by the [Accu M6 × 45 DIN 933 bolt specification](https://www.accu.co.uk/full-thread-hexagon-bolts/18876-SEBF-M6-45-A2), [Würth M6 DIN 934 nut specification](https://eshop.wuerth.de/Hexagon-nut-DIN-934-steel-I6I-I8I-plain-NUT-HEX-DIN934-I8I-WS10-M6/03106.sku/en/US/EUR/), and [Würth ISO 7089 washer dimensions](https://eshop.wuerth.de/-/515002106.sku/de/DE/EUR/). These are dimensional references, not a procurement requirement or supplier endorsement. Different nut standards and washer variants can change the length calculation; measure the actual hardware.

At each lid's outer face, the hole center is 8.85 mm from the start of the 2 mm outer bevel. A 12 mm washer leaves 2.85 mm of nominal flat material beyond its outside edge. A 10 mm-across-flats hex head/nut has an approximately 11.55 mm corner envelope, within that washer diameter. The geometry provides nominal footprint clearance; printer tolerances, washer centering, surface flatness, tool access, bearing strength, and actual hardware fit still need a dry-fit check. Do not add countersinks or nut traps. No clamping torque is validated.

## 2. Print and inspect

These are orientation suggestions to evaluate in a slicer, not tested settings. Printer, print material, nozzle, layer height, support process, and demonstrated mold lifetime are not established.

| Component | Suggested starting orientation | What to inspect before printing |
| --- | --- | --- |
| Top lid | Rotate so its broad exterior face is on the bed; posts and seating wall point upward | The exported lowest-Z surface is the core tips, not a useful default build face. Inspect ball undersides and thin ribs; supports must be removable without changing socket-forming surfaces. |
| Bottom lid | Broad exterior face on bed; seating wall upward | Preserve the flat pad-contact face, seating wall, and external opening bevels. |
| Center | Evaluate narrow column-side openings toward the bed and broad pad openings upward | Inspect every internal overhang and both bleed trenches. All support must remain accessible through the openings; reject a strategy that traps support or scars inaccessible cavity surfaces. |
| Panel | Flat back on bed, posts upward | Inspect the same ball undercuts and ribs as the top lid, plus flatness of the 2 mm panel base. |

Check mold footprint 130.6 × 130.6 mm, center thickness 16 mm, each lid body 8 mm, panel footprint 94.6 × 94.6 mm, 23.4 mm post pitch, nominal 5 mm ball diameter, 1.6 mm stem diameter, 0.6 mm rib thickness, and 4.6 mm rib outside diameter. Nominal post reach from its contact surface is 8.1 mm; see [validation](validation.md) for triangulated-mesh bounds.

Remove support remnants and loose debris. Inspect the 1.2 mm support-fin cavity features, post surfaces, seams, holes, and seating walls for damage or unintended blockage. Smoothness on the tooling becomes texture on the casting. Any coating changes dimensions; evaluate it on a trial first. Printed walls and parting faces are not assumed liquid-tight.

## 3. Dry-fit the stack and understand its faces

CAD render of the three mold pieces separated vertically

*CAD render, not a physical build: socket-core lid above the center piece, pad-face lid below. The upper lid's cores face downward and are mostly hidden by its body in this view. Scoring is disabled.*

The assembly coordinate system is useful even though each export has been moved onto Z ≥ 0:

```text
                       TOP LID: broad exterior faces upward
                       ball cores and seating wall point DOWN
center upper face z=16  narrow column/fins openings; sockets form here
                       silicone cavity, with pad at lower end
center lower face z=0   broad rounded-square PAD openings
                       BOTTOM LID: contact face and wall point UP
                       broad exterior faces downward
```

Seat the bottom lid's wall into the center's lower peripheral trench; align all four holes. Lower the top lid with its cores centered in the upper openings and its wall entering the upper trench. Each lid wall is nominally 2.6 mm wide in a 3 mm trench, with 0.2 mm modeled clearance on each side and **no extra nominal depth clearance**. Confirm full seating without force. Neither lid's wall height belongs on top of the closed 32 mm bolt-line stack.

Fit all bolts, washers, and nuts. Confirm each bolt passes freely, washers lie flat, threads project beyond the nuts, and the broad parting lands meet uniformly. Do not use bolt force to correct interference, warped faces, or blocked wall seats. Record any printer-dependent clearance problem before considering a separately reviewed geometry change.

Both center faces have peripheral overflow/bleed trenches. They are largely occupied by the seating walls when closed. The model does not contain a dedicated injection port or an independently validated vent network; the trenches are separated from the cavities by mold-face land. Do not assume a ring-shaped trench guarantees that trapped air can escape.

## 4. Select the material and run a small trial

**Shore 40A is the target cured hardness, not a complete formulation.** The owner uses the BBDINO product linked above. Its identity resolves the earlier product-selection gap; it does not validate its behavior in this mold. Do not substitute an older hardness, sealant, caulk, or urethane.

The [official BBDINO 40A product page](https://bbdino.com/products/bbdino-40a-clear-silicone-mold-making-trial-kit-gp-platinum-cure-high-hardness) reports the nominal specifications below. These are manufacturer product-page statements, not project measurements. A matching 40A TDS/SDS was not located through the [official downloads page](https://bbdino.com/pages/documents-download) during this review. Obtain the current documents for the delivered product and complete the unresolved fields before mixing:

| Required material/process information | Status |
| --- | --- |
| Product identity | Owner-linked BBDINO 40A clear silicone kit, ASIN B0FHHBGSQK; confirm delivered variant/batch |
| Nominal hardness / chemistry | Manufacturer page: Shore A 40 ± 2, platinum cure; suitability for this casting geometry requires trial |
| A:B ratio and measurement basis | Manufacturer page: 1A:1B by weight or volume; confirm supplied instructions and use one consistent measurement basis |
| Working time | Manufacturer page: about 30 minutes around 23°C; full mixing/pre-mixing method and batch limits require selected manufacturer's technical datasheet |
| Cure/demold time and any post-cure | Manufacturer page: about 3 hours cure around 23°C; demold criteria, temperature limits and post-cure require selected manufacturer's technical datasheet |
| Density, shrinkage and expected viscosity | requires selected manufacturer's technical datasheet |
| Print/coating compatibility; sealer and release products/procedure | requires selected manufacturer's technical datasheet |
| Vacuum degassing | Manufacturer page calls for vacuum degassing; equipment, procedure and timings require selected manufacturer's technical datasheet |
| PPE, ventilation, spill response, storage and disposal | requires selected manufacturer's technical datasheet **and safety data sheets for both parts and all treatments** |

Read the current official technical and safety documents for this BBDINO product. The Smooth-On references below provide general handling examples; their recipes are not instructions for BBDINO. The [Smooth-On document library](https://www.smooth-on.com/documents/) illustrates the separate technical-bulletin and SDS records to obtain.

Clean and fully prepare a small sample of the actual print material using the intended surface finish, coating, and release treatment. Cure a small silicone sample against it before committing to the mold. Check for tackiness, adhesion, coating transfer, and dimensional change. Surface contamination or treatment can inhibit cure, and a sealer is not a universal fix. [Smooth-On cure-inhibition guidance](https://www.smooth-on.com/support/faq/104/)

For the casting trial and subsequent batches, clean the actual cavity faces, both lids and every socket core using the compatible method established in the sample test. Apply any required sealer/release treatment according to its official instructions, including drying or curing time, and repeat the dry-fit after treatment. Avoid pooled treatment that obscures fine features. Release choice depends on the contacting materials; the sample result and selected product instructions govern this mold. [Manufacturer release guidance](https://support.smooth-on.com/knowledgebase.php?article=49)

After that compatibility check, cast **one existing cavity** with the full matched mold stack and trial demolding and attachment to one panel post. This reduces the batch while keeping the actual geometry. Assess complete pad/fin fill, socket/rib detail, leakage, and whether Shore 40A can stretch off the core and onto the panel without tearing or breaking a post. Do not interpret a successful cure coupon as proof of socket fit or full-array fill.

## 5. Measure and mix

Prepare the dry-fitted tooling and open-fill work area before combining components. Use the ventilation, eye protection, gloves and other precautions required by the selected SDS; glove material can itself affect compatibility, as illustrated by [Smooth-On's silicone handling instructions](https://www.smooth-on.com/products/smooth-sil-940/). Do not adopt that example product's temperatures, ratios or timings unless it is the product actually selected.

Measure A and B using one consistent measurement basis and a ratio explicitly permitted by the selected product. Confirm the supplied BBDINO instructions before using either advertised 1:1 option. Follow the product's mixing method and include the container sides and bottom; do not guess the ratio or extend working time with undocumented additives. [General manufacturer mixing guidance](https://support.smooth-on.com/knowledgebase.php?article=43)

BBDINO's linked product page calls for vacuum degassing. Obtain its detailed procedure and use purpose-built equipment according to its instructions, within the working time and with the prescribed expansion space. Degassing the mixture does not solve a blocked cavity air path. No pressure process or improvised pressure equipment is specified here. [General manufacturer explanation of degassing](https://support.smooth-on.com/knowledgebase.php?article=47)

### Quantity

Do not use the volume of the unsocketed `silicone_positive` export as the final material requirement. The calculation must use validated cavity solids and subtract the **intersection** of the socket-forming ball, stem, and four ribs with those cavities:

```text
net unit volume = cavity volume − volume displaced inside cavity by lid cores
batch volume = net unit volume × cavities filled
             + measured intentional overflow/flash volume + measured handling loss
batch mass = batch volume × selected product's documented mixed density
```

A temporary analysis of the unchanged source modules produced valid closed meshes for one positive unit and for `silicone_unit()` minus `ball_snap_post()`. The positive volume was 2,388.779 mm³; subtracting 85.209 mm³ of core intersection gives **2,303.570 mm³ (2.304 mL) per nominal socketed unit**, or **36.857 mL for 16**. This is a geometric part-volume estimate at the default tessellation, not a complete mixing quantity. It does not yet include cavity face-relief details, overflow, flash, or handling loss. See [validation](validation.md) for method and limits.

**TODO before a full batch:** account for the actual closed cavity's face relief, then measure overflow and mixing-container loss in the trial. The perimeter trench's gross volume is not the overflow allowance because the seating wall displaces most of it. No density, shrinkage correction, percentage allowance, or mass estimate is assumed. Record the trial's actual batch and leftover quantity for the next build.

## 6. Fill while open, then close and cure

The following sequence is inferred from cavity orientation and needs a physical trial:

1. Set the bottom lid exterior-down on a stable level surface. Seat the center with broad pad cavities down against that lid and narrow column openings upward. Leave the top lid off.
2. With the column-side mouths **open to the air**, fill the selected cavity or cavities with the mixed silicone. Work slowly enough to let displaced air return through the still-open mouths. Check the lower pad regions and eight fin cavities in the trial; a full-looking mouth does not prove these regions filled.
3. Lower the top lid evenly with its ball cores pointing down into the filled cavities. Air and excess silicone need to leave across the still-open parting gap **before** the lands and seating walls close. Do not immediately tighten the bolts or force a lid that resists seating. Stop the trial if the seating wall closes the available escape route too early, or if trapped air/leakage prevents complete fill; document the defect for a separate design review.
4. Once seating is confirmed, fit the four fastener sets and bring them up gradually and evenly in a diagonal sequence. Use only enough force to keep the verified faces seated; no torque specification is available. Watch for bowing and washer indentation. Do not pour into the completely sealed assembly.
5. Leave the stack supported and undisturbed for the selected product's specified cure under its specified conditions. Do not accelerate cure with unvalidated heating of printed tooling. Follow any required post-cure after confirming material and tooling compatibility.

## 7. Open and demold

After the specified cure, remove all nuts, washers and bolts. A proposed removal sequence is to support and invert the closed stack so the **top lid's broad exterior rests downward** and the pad-side bottom lid faces upward. Use the outer edge bevel as a lead-in for a blunt spatula to separate the bottom lid gently; keep the tool away from cavities, ribs and sealing lands.

The broad pads must exit through the **broad pad-side openings**. With the center and top lid supported, progressively free one pad and its fins, then ease its socket off the ball core. Support the silicone near the socket as access allows; do not yank on thin fins, twist the slender printed core, or lever a blade inside a socket. This one-at-a-time approach is proposed to avoid pulling all 16 undercuts at once. Its practicality with Shore 40A remains unverified. Stop if tearing, binding or post damage begins.

Remove the center when the units are free. Inspect both tooling faces, seating walls, posts and ribs before reuse. No successful reuse count is documented.

## 8. Trim, inspect and attach

CAD section preview of a ball post and the matching derived silicone socket

*CAD section preview: the post has four alignment ribs; the silicone unit has eight larger curved support fins. The socket shown here is derived by subtracting the shared post geometry for illustration; the source's `silicone_positive` mode does not include it. Fit and demolding remain untested.*

The source includes experimental scoring/perforation modules, but **all three scoring enable flags are false in the canonical defaults**. Therefore do not expect the matched default exports to provide scored flash. An explicitly enabled variant needs a new matched export set and separate interference/flash tests; the presence of teeth and pockets would still not establish precise or tool-free tearing.

Inspect any flash before removal. On a scrap section, assess where a tear propagates; stop if it enters the pad, fins, or socket. As a fallback, support the cured part on a cutting surface and trim small amounts with appropriate sharp scissors or a craft blade, keeping hands clear of the cutting path. Leave questionable material for review rather than nicking the socket or stretching a tear into a functional surface.

Reject uncured/tacky areas, voids at the socket or fin roots, torn fins, blocked rib recesses, or damaged posts. Align the four socket rib recesses with the panel's four post ribs and press each unit straight onto its matched post while supporting the panel. Do not force a poor fit. Record attachment/removal behavior and inspect for tears or cracked posts; no retention force, durability, protective performance or suitability for contact with the body is established.

Capture the dimensions, actual print settings/material, silicone product and lot, datasheet revisions, measured ratio, conditions, timing, batch quantity, treatment, and trial outcomes. Use the [photo handoff](photos.md) to document the process without exposing private details.

## 9. Fit underneath the desk and route cables

The intended installed orientation has the rigid panel's flat back facing upward against the desk underside, with the posts and silicone units downward. Use the owner-linked mounting tape only after checking its exact instructions and compatibility with both the actual printed material and desk finish. Record surface preparation, tape layout/contact area, application pressure and required dwell time from that tape's manufacturer; no universal values or overhead load rating are established here.

First trial the adhesive on a representative surface and inspect attachment before adding cable runs. Document cable placement, adjustment, any panel peeling or unit release, and the actual cable sizes and loading. Leave enough cable slack to avoid pulling on plugs or using the panel as an unverified strain-relief anchor. Do not infer a load rating from the listing title.

**Planned panel change:** add adhesive-fitting slits to the panel's bottom/back for easier fitting. They are not present in `panel_part()` or the current panel STL. Before a geometry change, establish the intended slit form, measured tape width/thickness, placement and clearance, remaining panel thickness, and any effect on post roots and adhesive contact. See the [pending change and validation plan](validation.md#planned-panel-mounting-change). No slit dimensions or new print orientation are assumed here.

A future demonstration video should show the real mounting and cable-routing process, distinguish the present panel from any later slit-equipped revision, and record the configuration used. The [photo and video handoff](photos.md) lists the planned shots; no video link is published yet.

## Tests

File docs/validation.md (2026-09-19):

# Validation and artifact inventory

Audit date: 2026-09-19. The current source was inspected and exported locally with **OpenSCAD 2021.01**; mesh measurements used Python 3.10.11 and NumPy 2.2.6. No original CAD geometry or original STL was changed. CAD renders are illustrations, not physical test evidence. See [parameters](parameters.md) for the complete configuration and [release checklist](release-checklist.md) for publication gates.

## Current release candidates

The source is [system_rev7_perforated_score.scad](../system_rev7_perforated_score.scad). Its audited defaults are 4 × 4, 22 mm pads, 23.4 mm pitch, eight silicone support fins, four post ribs, and all scoring switches off. Source SHA-256 and portable reproduction commands appear in the [manifest](../exports/rev7-default/manifest.json). This is an **incomplete printable set**: the center-piece export is withheld pending the mesh issue below.

| File / mode | Measured STL bounds (mm) | Connected components | Result / role |
| --- | --- | ---: | --- |
| [bottom_lid.stl](../exports/rev7-default/bottom_lid.stl) | 130.600006 × 130.600006 × 11 | 1 | Mesh checks pass; printed tooling |
| `center_piece` (no public STL) | 130.600006 × 130.600006 × 16 | 1 | **Withheld: 24 zero-area triangles** |
| [top_lid.stl](../exports/rev7-default/top_lid.stl) | 130.600006 × 130.600006 × 16.097620 | 1 | Mesh checks pass; printed tooling with socket cores |
| [panel.stl](../exports/rev7-default/panel.stl) | 94.599976 × 94.599976 × 10.097620 | 1 | Mesh checks pass; separate rigid panel |
| [silicone_positive_reference.stl](../exports/rev7-default/silicone_positive_reference.stl) | 92.199997 × 92.199997 × 16 | 16 | Mesh checks pass; **solid reference without sockets**, not tooling or finished silicone |

“Mesh checks pass” means finite vertices, no triangle area at or below 10⁻¹² mm², every exact-coordinate edge shared by two triangles, consistent oriented edges, positive signed component volumes, and the expected component count. The checker does not weld vertices or repair inputs. Intentional separate silicone-array members count as 16 solids. The panel and each mold component should be one solid.

These checks do not exhaustively test self-intersections, prove slicer suitability, printability, mold sealing, physical socket fit, Shore 40A behavior, cure compatibility, demolding, durability or flash removal. STL is unitless: import as millimeters and confirm dimensions. Small differences from analytical dimensions arise from tessellation and float32 serialization.

## Center-piece export gate

OpenSCAD's CGAL render reported `Simple: yes`; the exported center mesh has one connected component, no open/nonmanifold edges and consistent winding. However, **24 triangles are exactly collinear**, with three distinct vertices. They lie on the upper cavity-face relief plane at approximately z = 15.92 mm. The legacy center STL similarly contains 40 zero-area triangles. A clean render or edge-manifold test alone would miss this limitation.

An additional OFF export was actually run from the same source/mode. That OpenSCAD version writes approximately six significant digits in OFF: the output had 37,100 triangles, 116 exact zero-area triangles and 164 at or below the 10⁻¹² mm² threshold. It did not resolve the issue and is also withheld. This comparison does not establish whether all degeneracies originate in triangulation or coordinate rounding.

The raw candidates remain outside the publishable repository. Do not silently remove triangles or edit mechanical features to make a validator pass. The proposed next step is to compare a genuinely higher-precision export/triangulation against the same CGAL solid, then validate any replacement triangulation for closed topology, no degenerate faces, unchanged surface/volume and slicer interpretation. This is an export-quality investigation; no unintended solid overlap has been established. A mechanical change, if ultimately necessary, needs a separate proposal describing the affected face-relief geometry and owner approval. No source change was made here.

## Original and legacy artifacts

These originals remain locally preserved and are excluded from the proposed public archive. Their names do not establish a matched configuration.

| Existing original | Observed result | Status |
| --- | --- | --- |
| `system_rev7 (bottom_lid).stl` | 112.4 × 112.4 × 11 mm | Smaller than canonical tooling; stale/unmatched |
| `system_rev7 (center_piece).stl` | 112.4 × 112.4 × 16 mm; 40 degenerate triangles | Stale/unmatched; mesh-quality issue |
| `system_rev7 (top_lid).stl` | 112.4 × 112.4 × 16.09762 mm | Stale/unmatched; do not pair with new center/panel |
| `system_rev7 (top_lid) (no score).stl` | Same outer bounds; different volume from other old lid | Stale/unmatched variant; filename insufficient to recover overrides |
| `system_rev7 (panel).stl` | 76.399994 × 76.399994 × 11.09762 mm | Stale/unmatched; current panel is 94.6 wide and 2 mm thick |
| `Silicone_Positive_REV7.stl` | 16 components; matching current bounds; gross volume 38,220.456986 mm³ | Consistent with current positive bounds/volume, but triangle set differs; provenance unverified and sockets absent |
| `LSR_quote_package_v1/system_rev7_perforated_score.scad` | 3 × 3, 23.2 pitch, 3.8 margins, scoring enabled, 2.6 stem, 3 mm panel; other changes | Noncanonical legacy source |
| `LSR_quote_package_v1/generate_button_step_files.py` | Independent CadQuery reconstruction; 3 × 3, 2.8 mm pad, **zero support fins** | Not an export of current SCAD; not executed |
| Quote STEP/STL/PDF package | Generated from divergent scripts/settings; previously reported overlap | **Unverified legacy reference; excluded pending separate review** |

The original positive has 34,240 triangles; regeneration has 33,216. Their bounds agree and gross volumes differ by approximately 0.000036 mm³, but sorted triangle comparison at four decimal places does not match. That supports dimensional consistency, not proof of exact surface equivalence or original generation settings. Use the regenerated reference with recorded provenance.

The quote drawing script was inspected without execution. It reads literal constants from its CadQuery generator, so its schematic dimensions need not match either SCAD copy; it also carries the old Shore 15A industrial LSR target. Neither successful STEP import nor these drawings would resolve the reported geometry concern. No current STEP manufacturing download was created. Legitimate intersections that union fins, columns, pads and post stems into one solid are not evidence of a defect.

## Design-intent comparison

The current source implements separate printed panel and mold, eight curved silicone support fins, four post-alignment ribs, the shared panel/lid post module, three mold pieces, dual-face perimeter channels and seating walls, four corner through-holes, and outer 2 mm opening bevels. No carrier, printed female receiver, carrier clip, hex-nut trap or block ejector is implemented.

Two qualifications matter: scoring is present as code but **disabled in all current defaults**, and `silicone_positive` remains a solid external positive. The reusable-mold intent, complete filling/air escape, socket release and clean trimming are not demonstrated physical results. There is no dedicated cavity-to-perimeter vent network or injection port. Filling must take place while cavities are accessible; closing the lids does not establish an assured air-escape path.

## Nominal silicone volume

An analytical wrapper outside the repository called the unchanged `silicone_unit()` module and, separately, `difference() { silicone_unit(); ball_snap_post(); }`. These exports each passed closed one-component mesh checks and CGAL reported `Simple: yes`. The subtraction includes the stem, ball and all four alignment ribs as a union, so overlap is not double-counted.

| Quantity | Mesh volume |
| --- | ---: |
| One external positive | 2,388.778583 mm³ |
| One socket-bearing nominal part | 2,303.569969 mm³ |
| Core displacement per unit | 85.208613 mm³ |
| 16 socket-bearing nominal parts | **36.857120 mL** |

This is a **nominal part-volume estimate**, not the complete closed-mold void or a ready-to-mix batch quantity. It excludes face-relief/parting flash, residual perimeter-channel clearance volume, spills and mixing-container losses. Overflow allowance requires a measured trial; no arbitrary percentage is supplied. The owner has now identified a BBDINO 40A silicone product; documented mixed density and resulting mass remain TODO. See the [build guide](build-guide.md#quantity).

## Planned panel mounting change

The owner-approved application is under-desk cable routing and management. The panel back is intended to attach to the desk underside with the [owner-used adhesive](build-guide.md#owner-used-materials). Identifying the application and products does not add physical test evidence to the mesh checks above.

The requested future feature is adhesive-fitting slits in the panel's bottom/back. The current `panel_part()` is a union of the plain 2 mm panel base and its posts; it contains no slit cuts. This documentation update leaves the canonical source, all exported meshes and the CAD images unchanged.

The affected mechanical module would be `panel_part()` in the canonical SCAD, with its panel export, manifest and illustrations regenerated after an approved change. First establish the intended slit form and location, measured adhesive dimensions and handling clearance. Then assess remaining panel thickness, post-root clearance, contact area, print orientation and support access. Validate the resulting mesh and dimensions, dry-fit the actual tape, and trial mounting, removal and cable loading against the actual desk finish. No slit width, depth, spacing, tape load rating or tested bond strength is established. Keep this proposal separate from the center-mold export issue.

## Reproduce the checks

The files can be inspected without running any project scripts. For regeneration, the tools actually used in this preparation were:

| Task | Recorded environment |
| --- | --- |
| SCAD export and CAD views | OpenSCAD 2021.01 |
| Initial mesh inspection and volume calculations | Python 3.10.11, NumPy 2.2.6 |
| Documentation image composition | Python 3.12.14, Pillow 12.3.0 |
| Final local package checks | Python 3.12.14; packaging uses the standard library |

The scripts do not install dependencies automatically. `inspect_stl.py` and `export_rev7.py` require NumPy; `render_cad.py` requires Pillow and OpenSCAD. `package_review.py` requires only Python. These are recorded environments, not a claim that every other version works. The supplied `.gitattributes` preserves canonical SCAD bytes and binary assets across Git checkouts; changing source line endings would change its recorded hash even if the geometry stayed the same.

Use an already installed OpenSCAD CLI and Python with NumPy. This preparation did not install applications or run the bundled legacy executable. Read scripts before running them. The export script leaves candidates and raw diagnostics **outside the repository**, refuses a nonempty output folder, and returns a nonzero exit status if any mesh gate fails. The currently expected all-mode result includes the center failure above. It does not publish or promote candidates.

From the repository root, with `openscad` on PATH:

```powershell
python -B scripts/export_rev7.py --openscad openscad --output ../Hoplon-Arrays-candidates
```

If OpenSCAD is not on PATH, replace `openscad` with the installed CLI executable path locally; do not put machine-specific paths into public documents. The equivalent single-component command is:

```powershell
openscad --export-format binstl --hardwarnings -o ../Hoplon-Arrays-candidates/center_piece.stl -D 'tool_mode="center_piece"' system_rev7_perforated_score.scad
```

Create that external output directory first when using the direct command. For diagnostic OFF export, use the same command with output extension `.off` and omit `--export-format binstl`.

```powershell
python -B scripts/inspect_stl.py exports/rev7-default/bottom_lid.stl exports/rev7-default/top_lid.stl exports/rev7-default/panel.stl exports/rev7-default/silicone_positive_reference.stl
```

`inspect_stl.py` prints a JSON report using basenames; `--output` can save it to an external private review folder. Its `--compare` option compares rounded triangle sets and should not be interpreted as a complete geometric Boolean comparison. The export script was exercised on `bottom_lid`; its refusal to write candidates inside the repository was also checked. The other candidates were produced with the recorded direct OpenSCAD commands and inspected by the same checker.

## Checks still required

- Resolve the center STL export-quality gate and regenerate a complete matched set from a recorded source/configuration.
- Inspect every intended print in the chosen slicer: scale, layer preview, thin post ribs, supports, accessible removal surfaces and sealing faces.
- Verify the calculated M6 fastener selection against actual purchased hardware, hole fit and flat seating; no tightening torque has been established.
- Perform the small Shore 40A compatibility/socket trial and document material datasheet, print process, fill method, voids, socket stripping and flash trimming.
- Test the complete proposed fill/demold sequence before presenting it as demonstrated.
- Review licensing, history/privacy findings and the exact proposed public file list before authorizing publication.

General mesh self-intersection proof, robust mesh-to-mesh surface-equivalence testing, STEP-to-current-SCAD equivalence, slicer validation and physical testing were not completed. CadQuery/OCP, trimesh and manifold3d were unavailable in the inspected Python environments. Their absence did not prevent source, topology, volume and provenance checks with the installed tools.

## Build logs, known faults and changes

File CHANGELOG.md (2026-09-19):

# Changelog

## 0.1.0 — Prepared, not published

First prototype source release for Hoplon-Arrays, an under-desk cable-routing and cable-management system. This version identifies the release snapshot; the mechanical design remains rev7.

- Documented the unchanged canonical 4 × 4 SCAD configuration, eight silicone support fins, four post ribs, separate rigid panel, and three-piece mold.
- Added three regenerated, mesh-checked print candidates and a clearly labeled socketless silicone reference, with provenance manifests.
- Withheld the center-piece STL after detecting zero-area triangles; a complete printable mold set is not included.
- Added the proposed Shore 40A DIY guide, owner-used material links, calculated hardware, parameter inventory and validation limits.
- Added three current-CAD images, a physical-photo/video handoff, and a proposal for future panel-back adhesive-fitting slits.
- Added custom personal/noncommercial licensing, export/inspection/render tools, and an explicit release file list with archive integrity checks.
- Excluded original unmatched STLs, the legacy STEP/quote package, bundled executables, private audit records and Git metadata from the prepared archive. Original local files were preserved.

See [release notes](docs/release-notes.md) for the intended scope and known limitations. No publication date or tag is claimed until the owner authorizes and performs publication.

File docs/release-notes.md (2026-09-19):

# Hoplon-Arrays 0.1.0 — Prototype source release

**Prepared release notes; not yet published.** The proposed identifier is `0.1.0`, recorded in [VERSION](../VERSION). The CAD revision is still rev7. No Git tag or hosted release has been created.

Hoplon-Arrays is a modular system for routing and managing cables underneath a desk. Silicone units snap onto a separate rigid, printed panel, which attaches to the desk underside with adhesive. This initial snapshot shares the current design and build research so the project can be inspected and developed further.

## Included in this snapshot

- The unchanged canonical [rev7 SCAD source](../system_rev7_perforated_score.scad), with 4 × 4 units on 23.4 mm pitch, eight curved support fins per unit and four alignment ribs per post. Scoring is off by default.
- Three regenerated print candidates: [socket-core lid](../exports/rev7-default/top_lid.stl), [pad-face lid](../exports/rev7-default/bottom_lid.stl) and [separate rigid panel](../exports/rev7-default/panel.stl). They passed the documented computational mesh checks; physical printability and fit are not established.
- A [silicone positive reference](../exports/rev7-default/silicone_positive_reference.stl) that shows the external envelope but has **no socket**. It is not a finished silicone part or a required print.
- A [proposed DIY build guide](build-guide.md), [parameters](parameters.md), [validation and artifact inventory](validation.md), three CAD images and reproducible export/inspection/render scripts.
- Owner-used BBDINO 40A silicone and adhesive references, and a calculated candidate set of four M6 × 45 bolts, four nuts and eight washers, subject to dry-fit verification.
- The custom [personal/noncommercial license](../LICENSE.md). Business use, including internal business use, and paid/for-profit use are not granted by these terms. See [scope and legal limits](licensing.md).

## Known limitations

**This is not a complete printable mold kit.** The center mold piece is present in the SCAD source, but its STL is withheld because the regenerated mesh contains 24 zero-area triangles. The failed candidate is excluded from the release archive. [Export-quality investigation](validation.md#center-piece-export-gate)

The casting sequence is proposed, and the following remain unverified: selected printing settings, liquid-tight mold seating, cavity filling and air escape, release of Shore 40A sockets from the cores, snap durability, flash removal, adhesive retention and cable loading. Manufacturer product-page information is recorded, but a matching 40A TDS/SDS and several process/material values remain outstanding. The adhesive listing has conflicting specifications; measure the actual tape before designing around it.

The nominal socketed silicone volume is 36.857 mL for 16 units, excluding unmeasured flash, overflow and handling losses. It is not a final mixing quantity or a mass recipe. No physical test results or performance claims are inferred from the CAD renders.

The original root STLs and legacy quote/STEP/drawing package are excluded. The old meshes differ from the current source, and the quote geometry remains unverified. Do not combine them with this snapshot.

## Future updates

- Resolve the center-piece export issue and validate a complete matched set.
- Add physical build, fit, casting, adhesive and cable-routing evidence, with actual settings and measurements.
- Review and implement panel-back adhesive-fitting slits once their form and dimensions are established. They are **absent from this version**.
- Add the planned [photos and demonstration video](photos.md), including under-desk installation and cable adjustment.

To report a problem, include the source hash, version, parameter overrides, affected mode, tool versions and reproducible steps. For physical observations, include material/process details and privacy-checked images. Start with the [README](../README.md); publication actions are tracked separately in the [release checklist](release-checklist.md).
